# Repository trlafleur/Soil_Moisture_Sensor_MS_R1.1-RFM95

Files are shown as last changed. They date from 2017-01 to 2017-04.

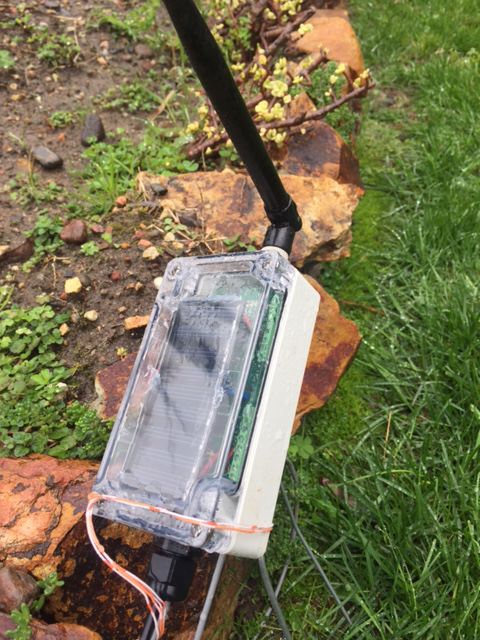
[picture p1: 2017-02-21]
Doc/IMG_5308.JPG

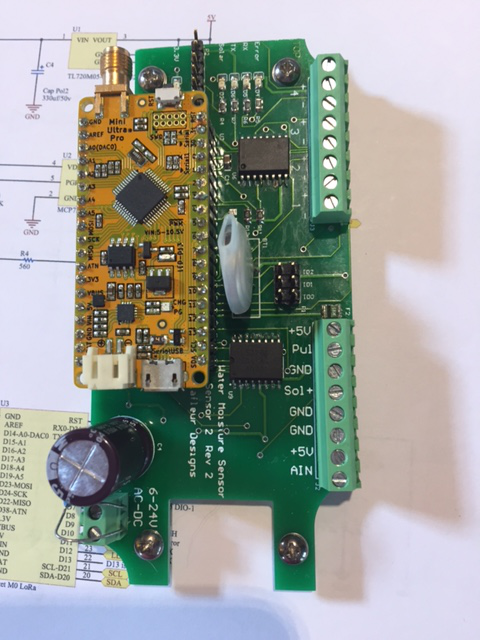
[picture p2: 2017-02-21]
Doc/IMG_5177.JPG

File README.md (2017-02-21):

# Soil_Moisture_Sensor_MS_R1.1-RFM95

This is a work in progress! , but most everything works.

~~~
This was developed with MySensor 2.1.1  https://www.mysensors.org/
IDE 1.81
SAMD 1.6.11
RocketScream M0 with RFM95 radio
~~~
Data from the sensor to MQTT-gateway to MQTT to (Telegraf to InFluxdb to Grafana) Controller function via NODE.RED connected via MQTT.

It measures soil moisture from 1 to 4 sensors, has options for soil and air temperature.

Support MCP9800 or Si7021 (humidity also) or temp sensor in DS3231 for air temp

DS18B20 for soil temp

Support of a water pressure sensor via an analog port

Has a DS3231 Real Time clock to wake up processor at designated hour

Has support on the board for a flow meter and pressure sensor (but no software in this code base)

Solar, battery Powered or via 8 to 28v AC or DC

Sleep's most of the time and just wakes up to see if its time to send a report.

Support for requesting and receiving time of day for setting RTC

Support for updating sensor tx schedule via V_VAR1

(Board is designed to fit in a Hammond 1554 case)

https://github.com/trlafleur/Soil_Moisture_Sensor_MS_R1.1-RFM95

Sensor are made from plaster of paris (gypsum)

http://vanderleevineyard.com/1/post/2012/07/the-vinduino-project-2-making-and-installing-gypsum-soil-moisture-sensors.html

http://www.irrometer.com/sensors.html#wm

https://www.amazon.com/Delmhorst-GB-1-Gypsum-Sensor-Moisture/dp/B0002IKRUS

Based on the work of: Reinier van der Lee, www.vanderleevineyard.com

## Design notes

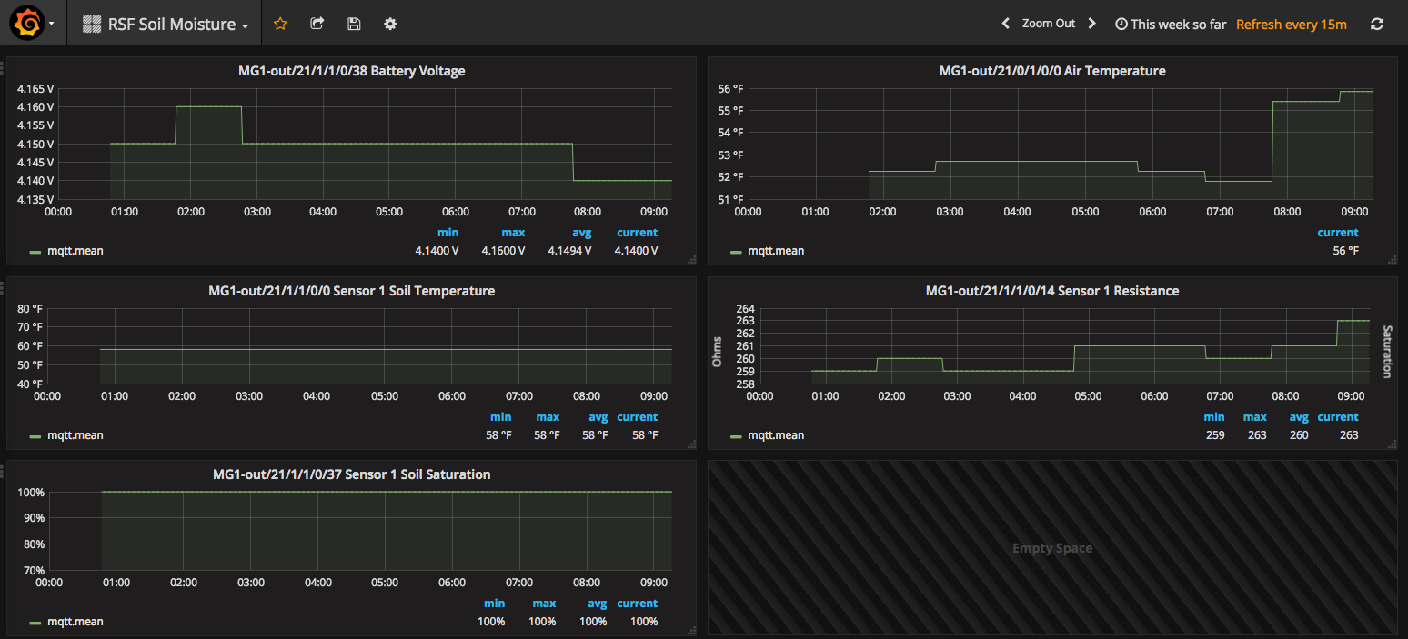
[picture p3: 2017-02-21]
Doc/Screen Shot 2017-02-19 at 9.16.37 AM.png

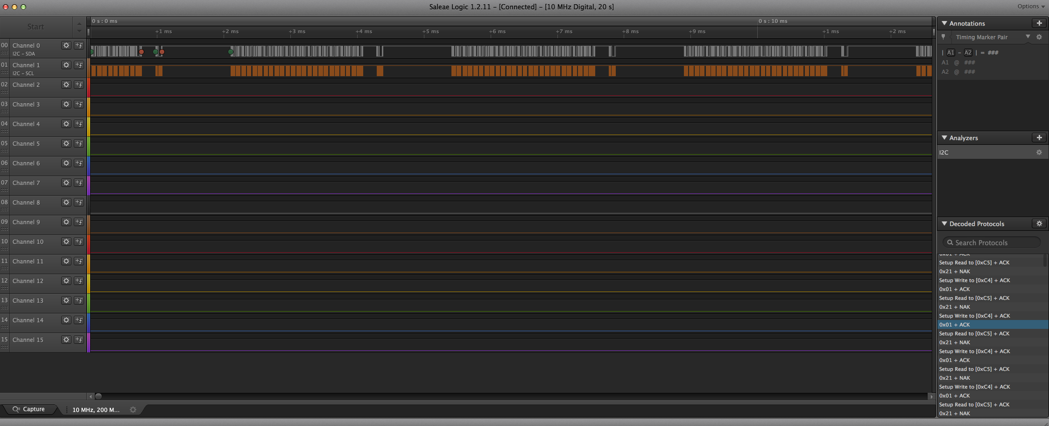
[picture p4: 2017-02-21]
Doc/Sensor_Disk as sent to fab 17Jan2017/Screen Shot 2017-01-31 at 7.55.02 AM.png

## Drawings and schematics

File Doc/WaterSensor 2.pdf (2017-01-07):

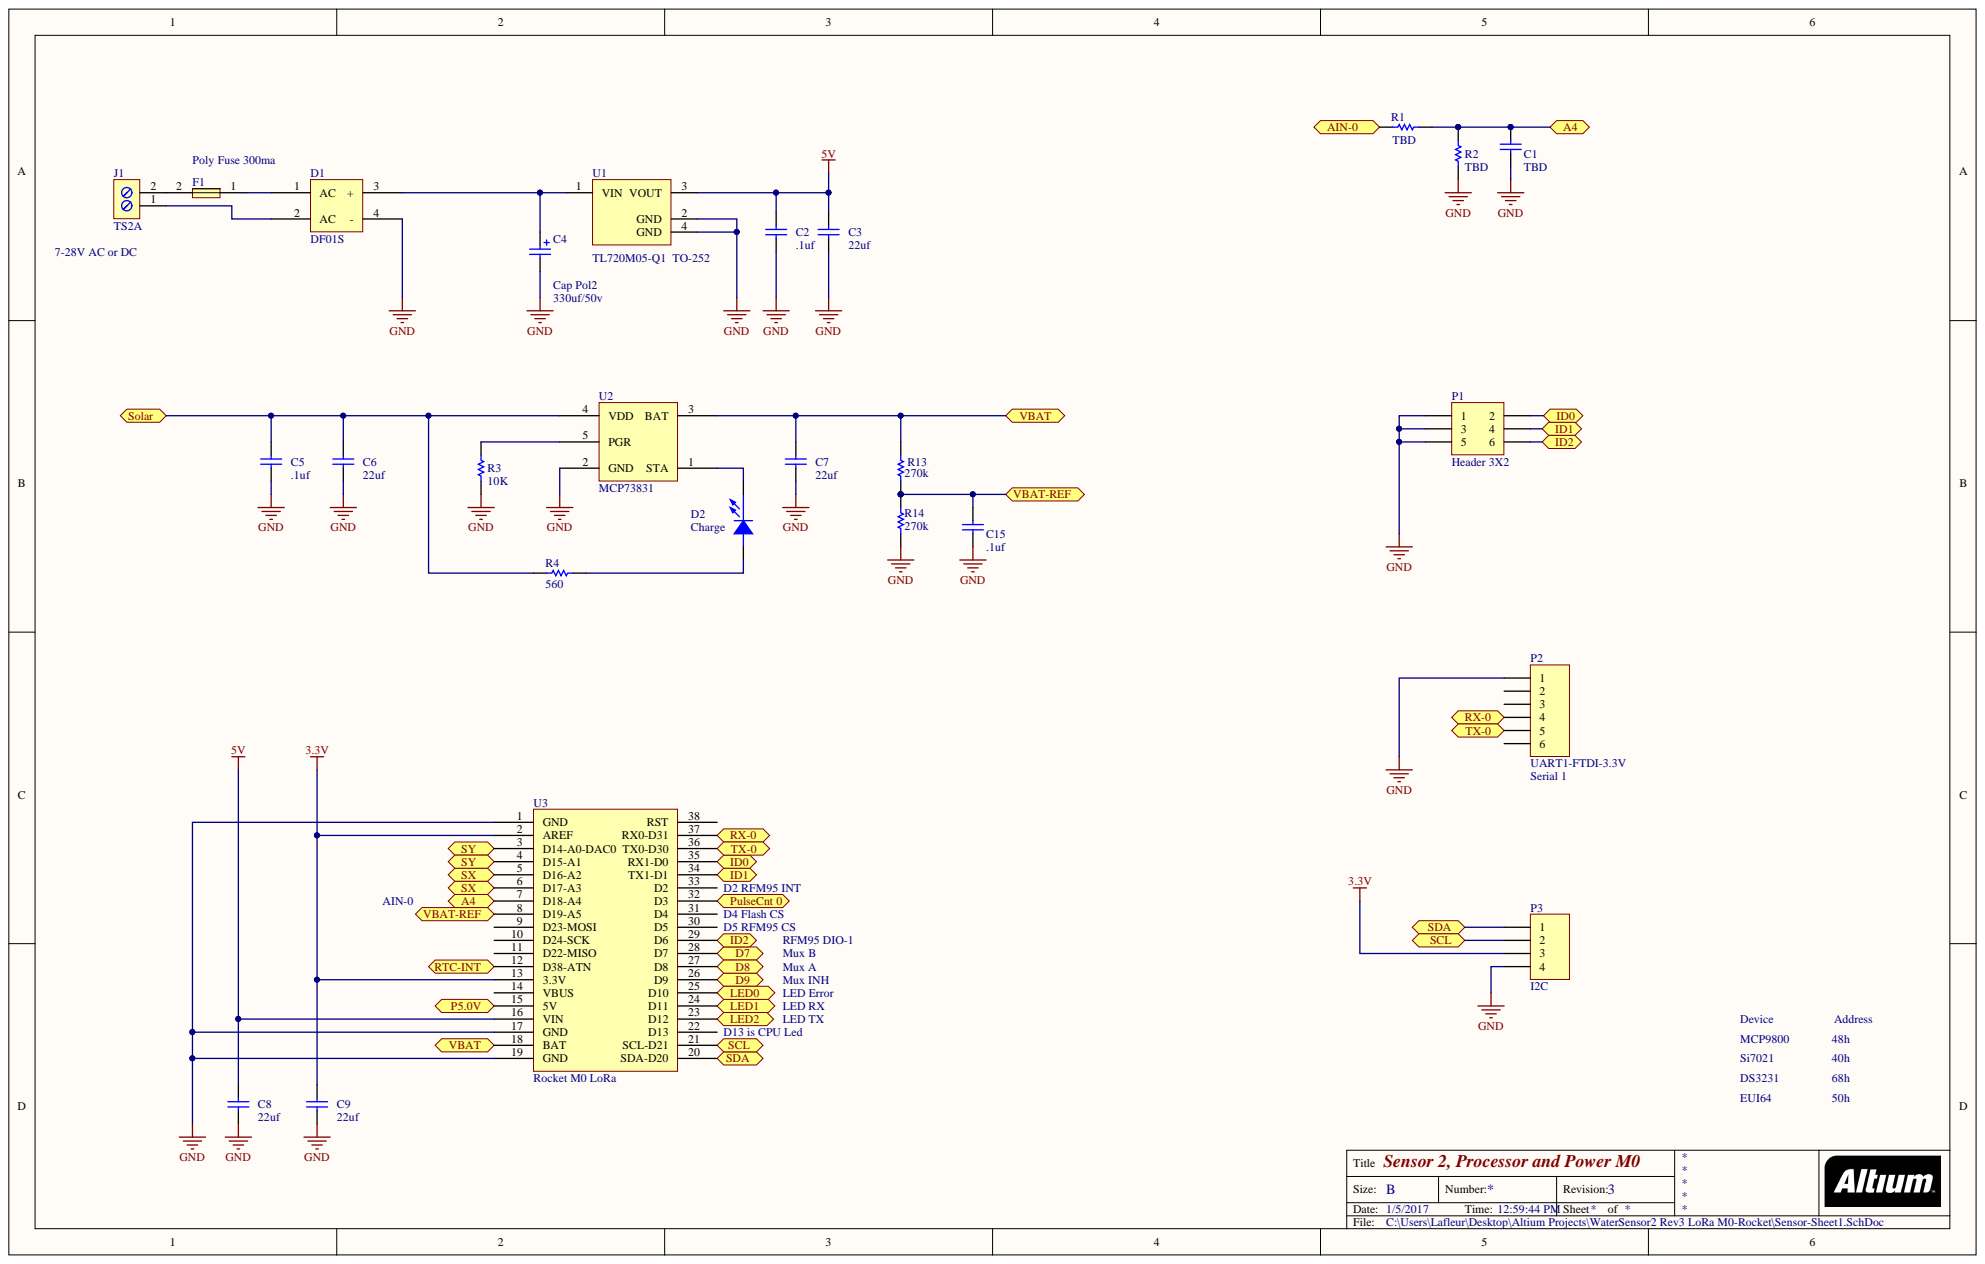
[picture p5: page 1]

B | GND GND GND | B

PGR 5

VBAT | BAT 18

Sensor 2, Processor and Power M0
Title

C:\Users\Lafleur\Desktop\Altium Projects\WaterSensor2 Rev3 LoRa M0-Rocket\Sensor-Sheet1.SchDoc

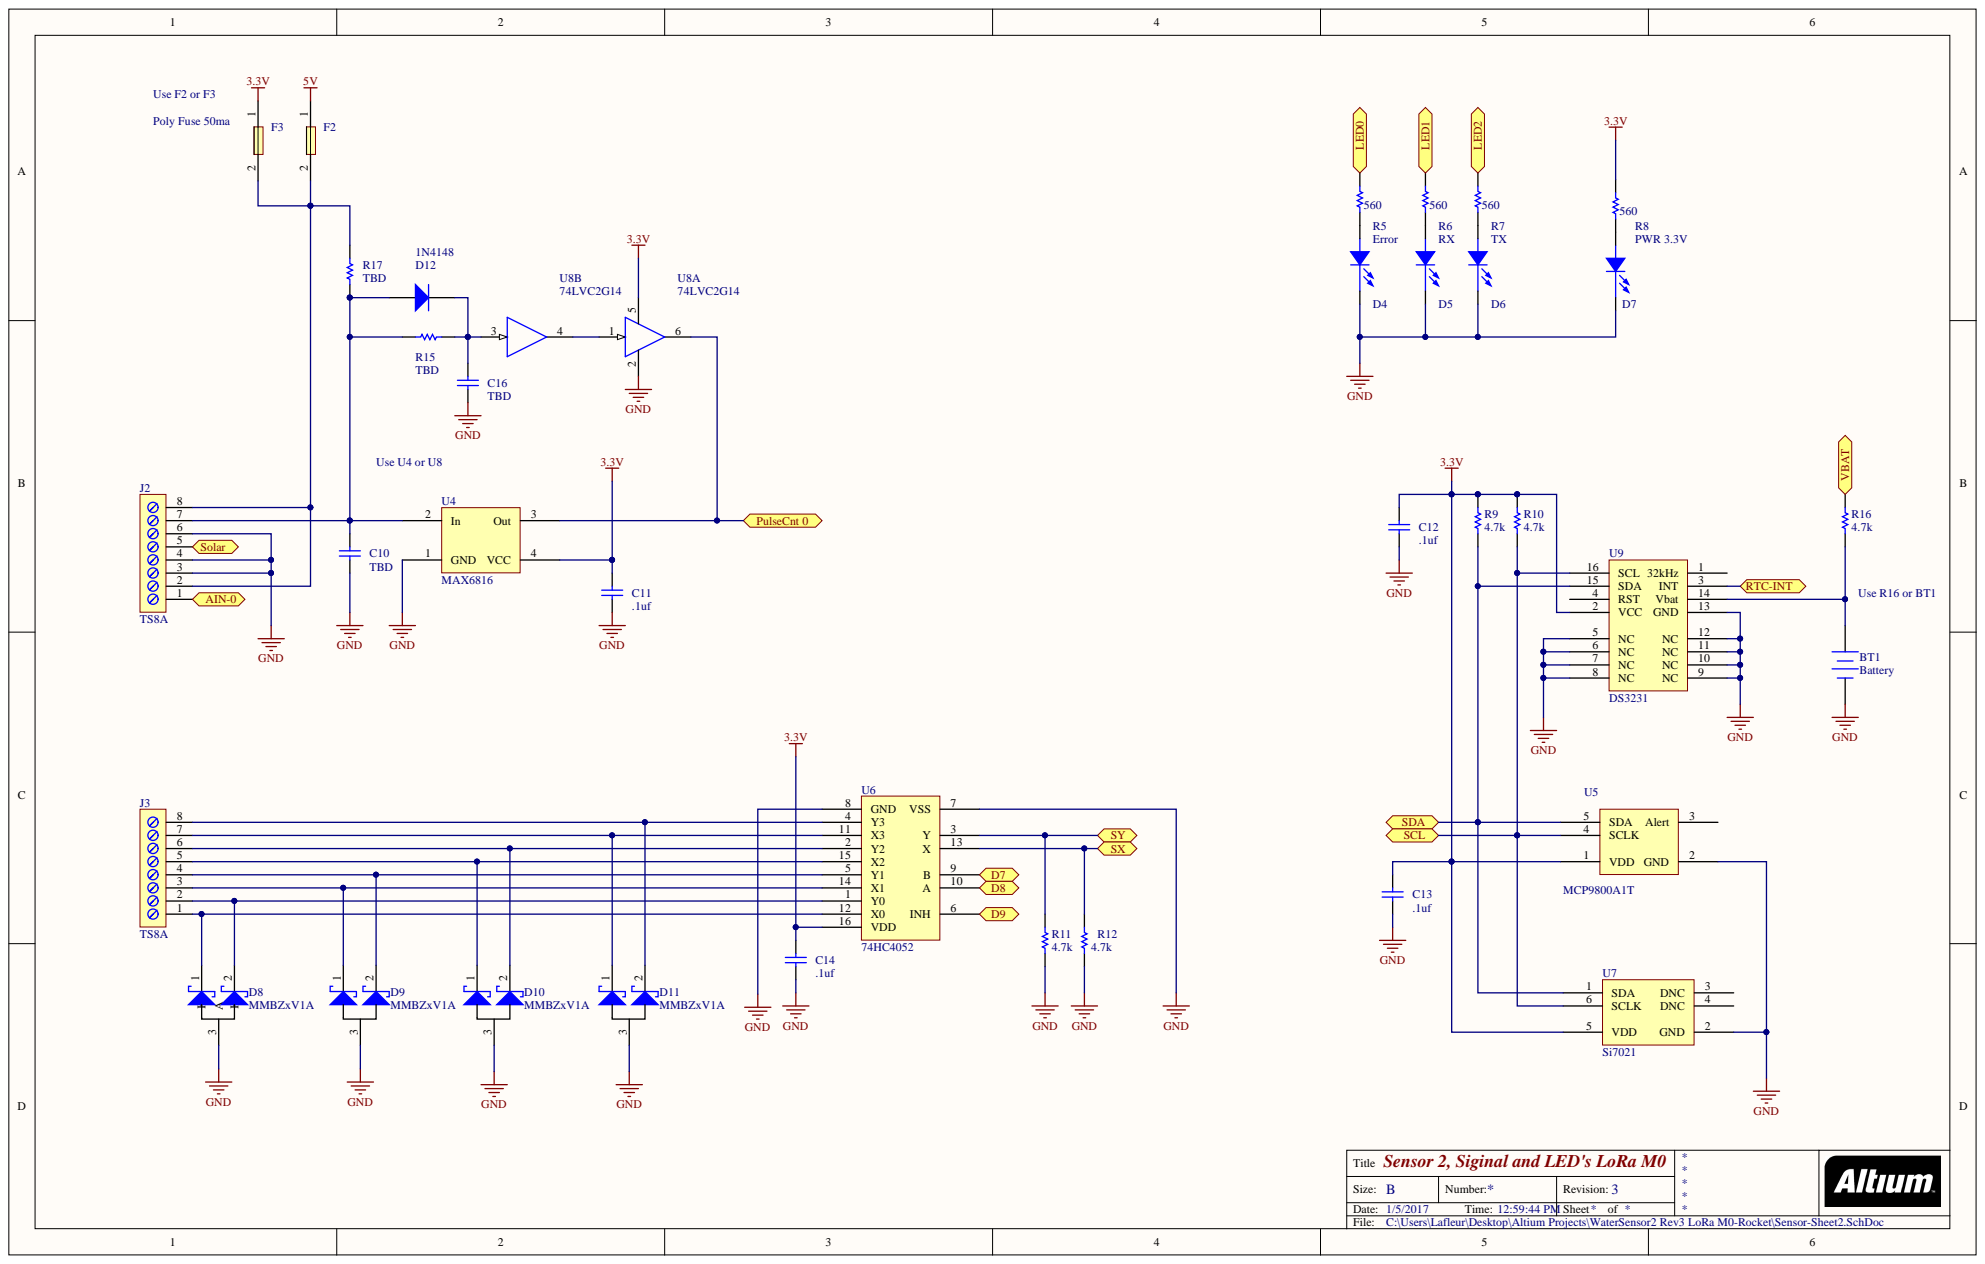
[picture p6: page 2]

1 2
1 6

Title | **** *

Size: B | Number: | Revisio n :

Date: Time: | | Sheet * o f *
File: C:\Users\Lafleur\Deskto p\Altium Projects\WaterSensor2 Rev 3 LoRa M0-Rocket\Sensor-Sheet2.SchDo | c

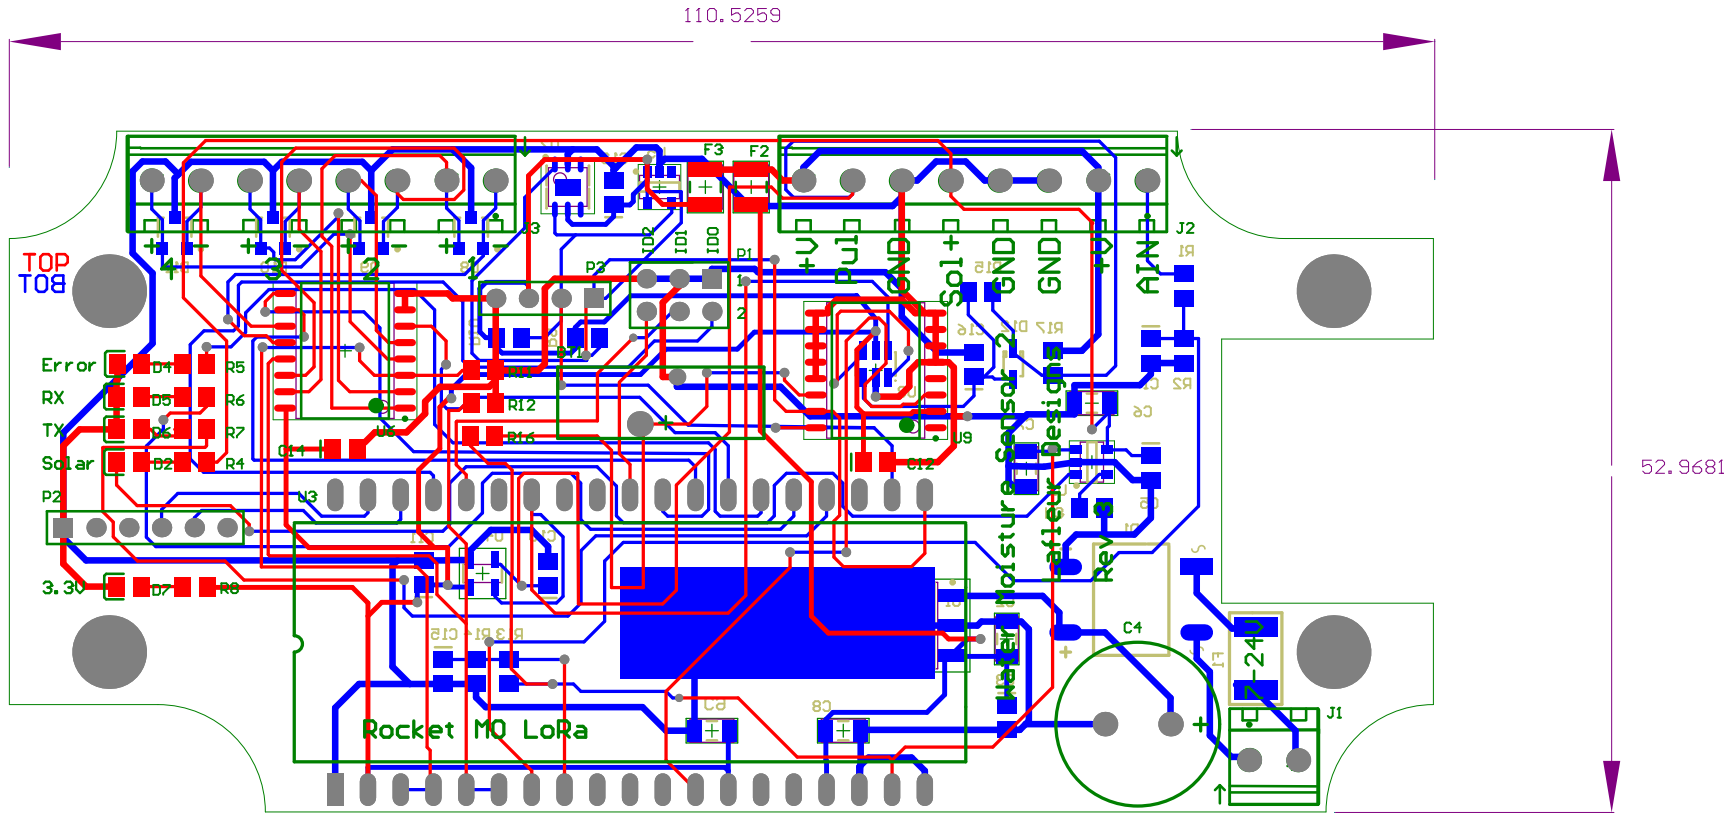
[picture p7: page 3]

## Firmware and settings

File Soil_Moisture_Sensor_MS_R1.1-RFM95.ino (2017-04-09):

/*  
 *  Soil Moisture Sensor
 *    4 channels
 *    Temperature + Humidity 
 *    1 Analog In
 *    1 Flow Counter In
 *    DS3232 RTC + Temperature
 *    DS18B20 Soil Sensor
 *  
 *  Water from a pressure transducer, 0 to 5v
 *    Input from sensor is scaled by .6577, 5.0v * .6577 = 3.288v
 *    (10.2k and a 19.6k resistor, filtered with a .1uf cap)
 *   
 *  Output: 0.5V – 4.5V linear voltage output. 0 psi outputs 0.5V, 50 psi outputs 2.5V, 100 psi outputs 4.5V 
 *    0   psi = 0.33v after scaling 5.0v to 3.3v
 *    50  psi = 1.65v
 *    100 psi = 2.97v
 *    3.3v/1023 = .003225806 volt per bit or 3.3V/4095 = .000805861 volts per bit
 *    
 *
 *    Max6816 is used as an option on Rev2a board to de-bounce the flow reed switch on the meter
 *    The switch must be stable for 40ms to get an output, this limits the max
 *    rate this device can support to less than 20Hz or so. (1,200 gpm)
 *
 *
 * CHANGE LOG:
 *
 *  DATE         REV  DESCRIPTION
 *  -----------  ---  ----------------------------------------------------------
 *  22-Dec-2016 1.0a  TRL - first 
 *  27-Dec-2016 1.1a  TRL - Added DS3232 and Moisture Mux code
 *  31-Dec-2016 1.1a  TRL - Changed freq to 928.5MHz
 *  04-Jan-2017 1.1b  TRL - Adding Sleep and (WDT code ??)
 *  07-Jan-2017 1.1c  TRL - Adding Soil Temp Sensor
 *  14-feb-2017 1.1d  TRL - Adding time of day request
 *  02-Mar-2017 1.1e  TRL - Added KeepAwake code and message
 *  22-Mar-2017 1.1f  TRL - Added calibration for sensor to % moisture
 *
 *  Notes:  1)  Tested with Arduino 1.8.1
 *          2)  Testing using RocketStream M0 with RFM95 & RFM95T
 *          3)  Sensor 2 board, Rev2a 
 *          4)  MySensor 2.1.1 30 Dec 2016
 *    
 *    
 *    MCP9800   base I2C address 0x40
 *    Si7021    base I2C address 0x48
 *    DS3231    base I2C address 0x68
 *    EUI64     base I2C address 0x50
 *    
 *    DS18B20   1Wire address 0x44?
 *    
 *    TODO:   done --> RFM95 and MySensor in sleep mode
 *            Flash in sleep mode
 *            done --> Sleep Mode
 *            WDT, issue is complicated due to sleep and MySensor
 *            done --> Set correct alarms time and functions
 *            done --> Send current time to board
 *            done --> DS18B20 Soil temp sensor
 *            done --> schedule update from controller
 *            done --> added KeepAwake code and message
 *    
 *    Based on the work of: Reinier van der Lee, www.vanderleevineyard.com
 */
/* ************************************************************************************** */

// Define's for the board options
#define R2a                     // Rev 2a of the board
//#define IDsize2                 // if using only ID0 and ID1. ID2 --> D6 is needed for LoRaWan code base on TTN with RFM95

// Select the Temperature and/or Humidity sensor on the board
//#define Sensor_SI7021         // if using the Si7021 Temp and Humidity sensor
//#define Sensor_MCP9800        // if using the MCP9800 temp sensor
//#define WaterPressure         // if we have a water pressure sensor
//#define WaterMeter            // if we have a water flow meter
#define MyDS18B20               // if using a Soil Temp sensor
//#define MyWDT                 // if using the Watch Dog Timer
#define MoistureSensor          // if using the Moisture Sensor, 4 channels
#define MyDS3231                // if using the DS3231 RTC
//#define SendHeartbeat         // if sending the heartbeat message
#define MY_SERIALDEVICE Serial  // this will override Serial port define in MyHwSAMD.h file

/* ************************************************************************************** */
#include <Arduino.h>
#include <Wire.h>
#include "LowPower.h"

#if defined MyDS3231
    #include <DS3231.h>
    #define DS3231Int 38            // Interrupt pin
#endif

#if defined Sensor_SI7021
    #include "i2c_SI7021.h"
    SI7021 si7021;
#endif

#if defined Sensor_MCP9800
    #include <MCP980X.h>            // http://github.com/JChristensen/MCP980X
    MCP980X MCP9800(0);
#endif

#if defined MyDS18B20
    #include <OneWire.h>
    #include <DallasTemperature.h>
    #define ONE_WIRE_BUS 18         // This is shared with AIN0 port
    OneWire oneWire(ONE_WIRE_BUS);
    DallasTemperature SoilTemp(&oneWire);
#endif

#if defined MyWDT
  // #include <avr/wdt.h>              // for watch-dog timer support
#endif

#if defined MoistureSensor
  #include <math.h>                 // Conversion equation from resistance to %
#endif 

/* *********************************************************************************************** 
 * A bit array to define the hour to wake up and send a sensor messages...
 *  (NodeID * 5 %) 60 is use for the alarm time within the hour, this offset TX time for each node
 ************************************************************************************************ */
 // we always take a sensor reading at MySendTime[0] --> or midnight
 //                    0  1  2  3  4  5  6  7  8  9 10 11 12 13 14 15 16 17 18 19 20 21 22 23
bool MySendTime[24] = {1, 1, 1, 1, 1, 1, 1, 1, 1, 1, 1, 1, 1, 1, 1, 1, 1, 1, 1, 1, 1, 1, 1, 1};
#define TXoffset 5            // used to set a TX offset so each node TX's at a different time

/* ********************************************************************************************** */
// Most of these items below need to be prior to #include <MySensor.h> 

/*  Enable debug prints to serial monitor on port 0 */
#define MY_DEBUG            // used by MySensor
//#define MY_SPECIAL_DEBUG
//#define MY_DEBUG_VERBOSE_RFM95 
#define MY_DEBUG1           // used in this program, level 1 debug
#define MY_DEBUG2           // used in this program, level 2 debug

#define SKETCHNAME      "Soil Moisture Sensor"
#define SKETCHVERSION   "1.1f"

/* ************************************************************************************** */
/* Enable and select radio type attached, coding rate and frequency
 *  
 *   Pre-defined MySensor radio config's
 *   
 * | CONFIG           | REG_1D | REG_1E | REG_26 | BW    | CR  | SF   | Comment
 * |------------------|--------|--------|--------|-------|-----|------|-----------------------------
 * | BW125CR45SF128   | 0x72   | 0x74   | 0x04   | 125   | 4/5 | 128  | Default, medium range SF7
 * | BW500CR45SF128   | 0x92   | 0x74   | 0x04   | 500   | 4/5 | 128  | Fast, short range     SF7
 * | BW31_25CR48SF512 | 0x48   | 0x94   | 0x04   | 31.25 | 4/8 | 512  | Slow, long range      SF9
 * | BW125CR48SF4096  | 0x78   | 0xC4   | 0x0C   | 125   | 4/8 | 4096 | Slow, long range      SF12
 */

#define RFM95_BW125CR48SF512  RFM95_BW_125KHZ | RFM95_CODING_RATE_4_8, RFM95_SPREADING_FACTOR_512CPS | RFM95_RX_PAYLOAD_CRC_ON, RFM95_AGC_AUTO_ON | RFM95_LOW_DATA_RATE_OPTIMIZE  //!< 0x78,0xc4,0x0C   // trl <------
#define RFM95_BW125CR48SF1024 RFM95_BW_125KHZ | RFM95_CODING_RATE_4_8, RFM95_SPREADING_FACTOR_1024CPS | RFM95_RX_PAYLOAD_CRC_ON, RFM95_AGC_AUTO_ON | RFM95_LOW_DATA_RATE_OPTIMIZE //!< 0x78,0xc4,0x0C

#define MY_RADIO_RFM95
#define MY_RFM95_MODEM_CONFIGRUATION    RFM95_BW125CR45SF128
//#define MY_RFM95_MODEM_CONFIGRUATION    RFM95_BW125CR48SF4096

#define MY_RFM95_TX_POWER               23      // max is 23
//#define MY_RF95_TCXO                          // If using an RFM95 with a TCXO
//#define MY_RFM95_ATC_MODE_DISABLED
#define MY_RFM95_ATC_TARGET_RSSI        (-70)
#define MY_RFM95_FREQUENCY              (928.5f)    // 928.5, 918.5

#define SendDelay                       250       // this is the delay after each send
#define AckFlag                         true     // if we are requesting an ACK from GW

/* ************************************************************************************** */
// Select correct defaults for the processor and board we are using
#ifdef __SAMD21G18A__                             // Using an ARM M0 Processor, Zero, Feather M0, RocketScream Mini Pro

//#define MY_RFM95_RST_PIN        0
#define MY_RFM95_IRQ_PIN          2               // IRQ
#define MY_RFM95_SPI_CS           5               // NSS

#define MY_DEFAULT_TX_LED_PIN     12              // Led's on the board
#define MY_DEFAULT_ERR_LED_PIN    10
#define MY_DEFAULT_RX_LED_PIN     11
#define OnBoardLed                13              // CPU Led
#define MY_WITH_LEDS_BLINKING_INVERSE

#define MY_OTA_FLASH_SS            4              // Flash chip on processor
#define MY_OTA_FLASH_JDECID       0x1F65          // Rocket M0?? 0x0101??

#define ID0                        0              // ID pin
#define ID1                        1
#define ID2                        6

#else
  #error ********* Processor not defined, Requires an ARM M0 SAMD21G18A
#endif

/* ************************************************************************************** */

//#define MY_REPEATER_FEATURE

/* ************************************************************************************** */
// Set node defaults
#define NodeID_Base          20         // My Node ID base... this plus IDx bits
int myNodeID =                0;        // Set at run time from jumpers on PCB
#define MY_NODE_ID myNodeID             // Set at run time from jumpers

#define CHILD_ID0             0         // Id of my Sensor
#define CHILD_ID1             1         // Id of my Water sensor child
#define CHILD_ID2             2         // Id of my 2nd sensor child
#define CHILD_ID3             3         // Id of my 3rd sensor child
#define CHILD_ID4             4         // Id of my 4th sensor child

/* ************************************************************************************** */
/* These are use for local debug of code, hwDebugPrint is defined in MyHwATMega328.cpp */
#ifdef MY_DEBUG1
#define debug1(x,...) hwDebugPrint(x, ##__VA_ARGS__)
#else
#define debug1(x,...)
#endif

#ifdef MY_DEBUG2
#define debug2(x,...) hwDebugPrint(x, ##__VA_ARGS__)
#else
#define debug2(x,...)
#endif


/* ************************************************************************************** */
// All #define above need to be prior to the #include <MySensors.h> below
#include <MySensors.h>
/* ************************************************************************************** */
#include <core/MyTransport.h>

/* ************************************************************************************** */
#define PressPin      A4                            // Pressure sensor is on analog input, 0 to 100psi
#define BattVolt      A5                            // Battery Voltage on pin A5.  270k/270k divider = 1/2,  6.6v max

/* ************************************************************************************** */

MyMessage LEVEL1         (CHILD_ID1,V_LEVEL);       // 37 0x25      // Send Water Saturation Ch 1
MyMessage LEVEL2         (CHILD_ID2,V_LEVEL);       // 37 0x25      // Send Water Saturation Ch 2
MyMessage LEVEL3         (CHILD_ID3,V_LEVEL);       // 37 0x25      // Send Water Saturation Ch 3
MyMessage LEVEL4         (CHILD_ID4,V_LEVEL);       // 37 0x25      // Send Water Saturation Ch 4

MyMessage IMP1           (CHILD_ID1, V_IMPEDANCE);  // 14 0x0E      // Send Resistance Ch 1
MyMessage IMP2           (CHILD_ID2, V_IMPEDANCE);  // 14 0x0E      // Send Resistance Ch 2
MyMessage IMP3           (CHILD_ID3, V_IMPEDANCE);  // 14 0x0E      // Send Resistance Ch 3
MyMessage IMP4           (CHILD_ID4, V_IMPEDANCE);  // 14 0x0E      // Send Resistance Ch 4

MyMessage VBAT           (CHILD_ID0, V_VOLTAGE);    // 38 0x26      // Send Battery Voltage

MyMessage PressureMsg    (CHILD_ID0,V_PRESSURE);    // 04 0x04      // Send current Water Pressure
MyMessage TextMsg        (CHILD_ID0,V_TEXT);        // 47 0x2F      // Send status Messages
MyMessage HumMsg         (CHILD_ID0,V_HUM);         // 01 0x01      // Send current Humidity 
MyMessage TempMsg        (CHILD_ID0,V_TEMP);        // 00 0x00      // Send current Air Temperature
MyMessage ScheduleUpdate (CHILD_ID0,V_VAR1);        // 24 0x18      // Request a schedule update from controller

MyMessage SoilTempMsg    (CHILD_ID1,V_TEMP);        // 00 0x00      // Send current Soil Temperature
 

/* ************************************************************************************** */

#if defined MyDS3231
  DS3231 clock;
  RTCDateTime dt;
  boolean isAlarm = false;
  boolean alarmState = false;
  boolean alarmUpdateFlag = true;         // Its time to request an update for RTC if true
#endif

/* *************************** Forward Declaration ************************************* */
void SendPressure();
void SendKeepAlive();
void getTempSi7021();
void getTempMCP9800 ();
void receive(const MyMessage &message);
void receiveTime(unsigned long ts);
void hexdump(unsigned char *buffer, unsigned long index, unsigned long width);
int  GetMoisture(unsigned long read);
void soilsensors();
void measureSensor();
void addReading(long resistance);
long average();
void printCpuResetCause();
void systemSleep();
void systemWakeUp();

/* ************************************************************************************** */
unsigned long SEND_FREQUENCY        = 15000;      // Minimum time between send (in milliseconds). We don't want to spam the gateway.
unsigned long KEEPALIVE_FREQUENCY   = 120000;     // Send Keep Alive message at this rate

unsigned long currentTime         = 0;
unsigned long lastSendTime        = 0;
unsigned long keepaliveTime       = 0;

#define StayAwakeTime 5000                        // Stay Awake time before sleeping

bool KeepAwakeFlag = false;
#define KeepAliveID      0x5aa5
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
void loop()     
{ 
  //wdt_reset();
   
    currentTime = millis();                                    

 /* ***************** Send Sensor Data ***************** */
#ifndef  MyDS3231   // this is used for debug only, it allows us to send data at a faster rate

    if (currentTime - lastSendTime >= SEND_FREQUENCY)          // Only send values at a maximum rate (used for debug)
    {
      debug1(PSTR("\n*** Sending Sensor Data\n")); 
     
#else
            
    if ((MySendTime[dt.hour] == 1)  || (dt.hour == 12))         // See if it time to send data, we always send at noon
    {
      if (dt.hour == 12) KeepAwakeFlag = false;                // we only want to keep awake till noon
      systemWakeUp();                                          // we have work to do, so wake up radio and transport
      debug1(PSTR("\n*** Sending Sensor Data at: %u:%02u:%02u\n"), dt.hour, dt.minute, dt.second); 

        if (alarmUpdateFlag == true)                           // if its time, request time update from controller
        {
          debug1(PSTR("\n*** Requesting Time\n")); 
          alarmUpdateFlag = false;
          requestTime();  wait(SendDelay);                      // Ask controller for time of day
          wait (2000);
        }
#endif

      lastSendTime = currentTime;
       
      // Request a TX Schedule update at this time...
      debug1(PSTR("\n*** Requesting Schedule Update\n")); 
      send(ScheduleUpdate.set(1,0), AckFlag);  wait(SendDelay);
      wait (2000);
      
      soilsensors(); 
      int vbat = analogRead(BattVolt);                        // we will do it twice, junk the 1st read
      vbat = analogRead(BattVolt);
      float Vsys =  vbat * 0.000805664 * 1.97;                // read the battery voltage, 12bits = 0 -> 4095, divider is 1/2, so max = 6.6v
      send(VBAT.set(Vsys, 2), AckFlag);  wait(SendDelay);
      sendBatteryLevel(vbat/41);  wait (SendDelay);           // Send MySensor battery in %, count / 41 = 4095/41 = 99%
      floatMSB = Vsys * 100;                                  // we don't have floating point printing in debug print
      floatR = floatMSB % 100; 
      debug1(PSTR("Vbat: %0u.%02uV \n"), floatMSB/100, floatR);

      SendKeepAlive(); 
      
      wait (StayAwakeTime);                                    // Stay awake time
    }
     
#ifdef MyDS3231
     if ( KeepAwakeFlag == false)                              // see if keep alive flag is not set
     {
      systemSleep();                                           // ok, it bedtime, go to sleep
         // Ok, its wake up time....
      dt =  clock.getDateTime();                               // get current time from DS3231 
      debug1(PSTR("\n*** Waking From Sleep at: %u:%02u:%02u\n"), dt.hour, dt.minute, dt.second);
     }   
#endif
                       
}   // end of loop 



/****************** Message Receive Loop ***************************
 * 
 * This is the message receive loop, here we look for messages address to us 
 * 
 * ***************************************************************** */
void receive(const MyMessage &message) 
{
//   debug2(PSTR("*** Received message from gw:\n"));
//   debug2(PSTR("*** Last: %u, Sender: %u, Dest: %u, Length: 0x%02x, Ack: 0x%02x, Type: %u, Child ID: %u\n"), message.last, message.sender, message.destination, message.version_length, message.command_ack_payload, message.type, message.sensor);
//
//  uint8_t AckCmd =   (message.command_ack_payload &  0b00000111);
//  uint8_t AckReq =   ( (message.command_ack_payload &  0b00001000) >> 3);
//  uint8_t AckAck =   ( (message.command_ack_payload &  0b00010000) >> 4);
//  uint8_t AckType =  ( (message.command_ack_payload &  0b11100000) >> 5);
//  debug2(PSTR("*** Ack Cmd: 0x%02x, Ack Req: 0x%01x, Ack: 0x%01x, Ack Type: 0x%02x\n"), AckCmd, AckReq, AckAck, AckType);
//
//  uint8_t LenVer = (message.version_length & 0b00000011);
//  uint8_t LenSgn = ( (message.version_length & 0b00000100) >> 2);
//  uint8_t LenLen = ( (message.version_length & 0b11111000) >> 3);
//  debug2(PSTR("*** Ver: 0x%02x, Signing Flag: 0x%01x, Length: 0x%02x,\n"), LenVer, LenSgn, LenLen);

if (message.command_ack_payload & 0b00010000)                       // check to see if this is an ACK, if it is, return
    {
      //debug2(PSTR("*** Received ACK from GW:\n"));
    return;
    }
    
  
// Make sure its for our child ID
  if (message.sensor == CHILD_ID0 )
  {
    if  (message.type==V_VAR1)                                        // (24) This will received a new schedule time to send sensor data
      {
       unsigned long newSchedule = message.getULong();
       debug2(PSTR("*** Received V_Var1, newSchedule message: 0x%02x\n"), newSchedule );
       
       for (i=0; i< 23; i++)                                          // set MySendTime from newSchedule
        {  
          MySendTime[i] = ((newSchedule >> i) & 0x00000001);
        }          
      }
    
     if ( message.type==V_VAR2)                                       // (25) This will received a "do not sleep flag", that keep us awake until noon each day
      {
        unsigned int flag = message.getUInt();
        if (flag == KeepAliveID) KeepAwakeFlag = true;                // check for special ID      
        debug2(PSTR("*** Received V_VAR2, Keep Awake message: 0x%02x\n"), flag );
      }
    
     if ( message.type==V_VAR3)                                       // (26)
      {
      
        debug2(PSTR("*** Received V_VAR3 message from gw"));
      }

     if ( message.type==V_VAR4)                                       // (27)
      {
        debug2(PSTR("*** Received V_VAR4 message from gw\n") );
      }
    }  // end if (message.sensor == CHILD_ID1 )


 // Check for any messages for child ID = 1
  if (message.sensor == CHILD_ID1 )
    {
      debug2(PSTR("*** Received Child ID-1 message from gw. \n"));
    }
}  // end of received()


/* ***************************************************************** */
void receiveTime(unsigned long ts)
{
  debug1(PSTR("*** Received Time from gw: %lu \n"), ts);

#ifdef MyDS3231
  // Set from UNIX timestamp
    clock.setDateTime(ts);                              // Set time in DS3231
    dt =  clock.getDateTime();                          // Set time in system clock
#endif
}


/* ******************************************************** 
 *  
 *  Based on the work of: Reinier van der Lee, www.vanderleevineyard.com
 *     
 ********************************************************** */
void soilsensors()
{
// Select sensor 1, and enable MUX
  digitalWrite(MuxA, LOW); 
  digitalWrite(MuxB, LOW); 
  digitalWrite(MuxINH, LOW); 
  measureSensor();
  read1 = average();

    moisture = GetMoisture(read1);
    debug1(PSTR("Moisture 1: %u Res: %u\n"), moisture, read1);
    send(LEVEL1.set(moisture), AckFlag);  wait(SendDelay);
    send(IMP1.set(read1), AckFlag);  wait(SendDelay);

// Select sensor 2, and enable MUX
  digitalWrite(MuxA, HIGH); 
  digitalWrite(MuxB, LOW); 
  digitalWrite(MuxINH, LOW); 
  measureSensor();
  read2 = average();

    moisture = GetMoisture(read2);
    debug1(PSTR("Moisture 2: %u Res: %u\n"), moisture, read2);
    send(LEVEL2.set(moisture), AckFlag);  wait(SendDelay);
    send(IMP2.set(read2), AckFlag);  wait(SendDelay);

    // Select sensor 3, and enable MUX
  digitalWrite(MuxA, LOW); 
  digitalWrite(MuxB, HIGH); 
  digitalWrite(MuxINH, LOW); 
  measureSensor();
  read3 = average();

    moisture = GetMoisture(read3);
    debug1(PSTR("Moisture 3: %u Res: %u\n"), moisture, read3);
    send(LEVEL3.set(moisture), AckFlag);  wait(SendDelay);
    send(IMP3.set(read3), AckFlag);  wait(SendDelay);


  // Select sensor 4, and enable MUX
  digitalWrite(MuxA, HIGH); 
  digitalWrite(MuxB, HIGH); 
  digitalWrite(MuxINH, LOW); 
  measureSensor();
  read4 = average();

    moisture = GetMoisture(read4);
    debug1(PSTR("Moisture 4: %u Res: %u\n"), moisture, read4);
    send(LEVEL4.set(moisture), AckFlag);  wait(SendDelay);
    send(IMP4.set(read4), AckFlag);  wait(SendDelay);

  digitalWrite(MuxINH, HIGH);             // Disable Mux, this will isolate CPU from Sensor

  return;
}


/* ******************************************************** */ 
int GetMoisture(unsigned long read)
{
    // this equation changes based on calibration of sensors
    //int moisture = min( int( pow( read /  31.65 , 1.0 / -1.695 ) * 400 + 0.5 ) , 100 ); 
      int moisture = min( int( pow( read / 396.37 , 1.0 / -1.644 ) * 100 + 0.5 ) , 100 );
    if (moisture < 0)   moisture = 0;
    if (moisture > 100) moisture = 100;
  return moisture;
}
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

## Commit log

2017-01-03 added Reinier van der Lee credit
2017-01-05 Added sensor send time
2017-01-05 Moved Print Reset Cause
    [Soil_Moisture_Sensor_MS_R1.1-RFM95.ino]
2017-01-07 Added Schematic to package, fix some DS18B20 code, need to test
    [Soil_Moisture_Sensor_MS_R1.1-RFM95.ino]
2017-01-07 Testing DS18B20 code, not working yet, Issue with M0 I think
    [Soil_Moisture_Sensor_MS_R1.1-RFM95.ino]
2017-01-08 Fix to DS18B20 code
    [Soil_Moisture_Sensor_MS_R1.1-RFM95.ino]
2017-01-08 Corrected mux ordering in soil sensor
    [Soil_Moisture_Sensor_MS_R1.1-RFM95.ino]
2017-01-10 added power point
2017-01-15 Setup for yard test, fixed analog reference
    [Soil_Moisture_Sensor_MS_R1.1-RFM95.ino]
2017-01-17 fixed DS18B20 printing of -values in debug1 function
    [Soil_Moisture_Sensor_MS_R1.1-RFM95.ino]
2017-01-17 Added Sensor Disk PDF and Gerbers
    [PCB1.GBL, PCB1.GBO, PCB1.GBS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]
2017-02-19 Fixed code to always send a sensor report at Midnight
    [Soil_Moisture_Sensor_MS_R1.1-RFM95.ino]
2017-02-21 Added doc and photos
    [PCB1.GBL]
2017-03-04 Rework of cpu reset logic
    [Soil_Moisture_Sensor_MS_R1.1-RFM95.ino]
